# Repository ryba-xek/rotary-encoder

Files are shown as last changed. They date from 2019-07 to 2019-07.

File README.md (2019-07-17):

# rotation-sensor
Multipole AS5047D motor shaft sensor emulating standard UVW hall effect sensor signals

Please note, that AS5047d position is shifted by 1mm from the center of the board.

Emulates Hall sensors UVW signals for 14-pole BLDC motor.

## Building
`platformio run -e ATMEGA328P`

## Flashing
This code is supposed to be uploaded via standard AVR ISP programmer.
Please set fuses to `L=0xF7 H=0xD9 E=0xFF`

`avrdude -c usbasp -p m328p -P usb -e -U lfuse:w:0xF7:m -U hfuse:w:0xD9:m -U efuse:w:0xFF:m`

http://eleccelerator.com/fusecalc/fusecalc.php?chip=atmega328p&LOW=F7&HIGH=D9&EXTENDED=FF&LOCKBIT=FF

upload with `platformio run -t program -e ATMEGA328P`

## Testing
`platformio test -e native`

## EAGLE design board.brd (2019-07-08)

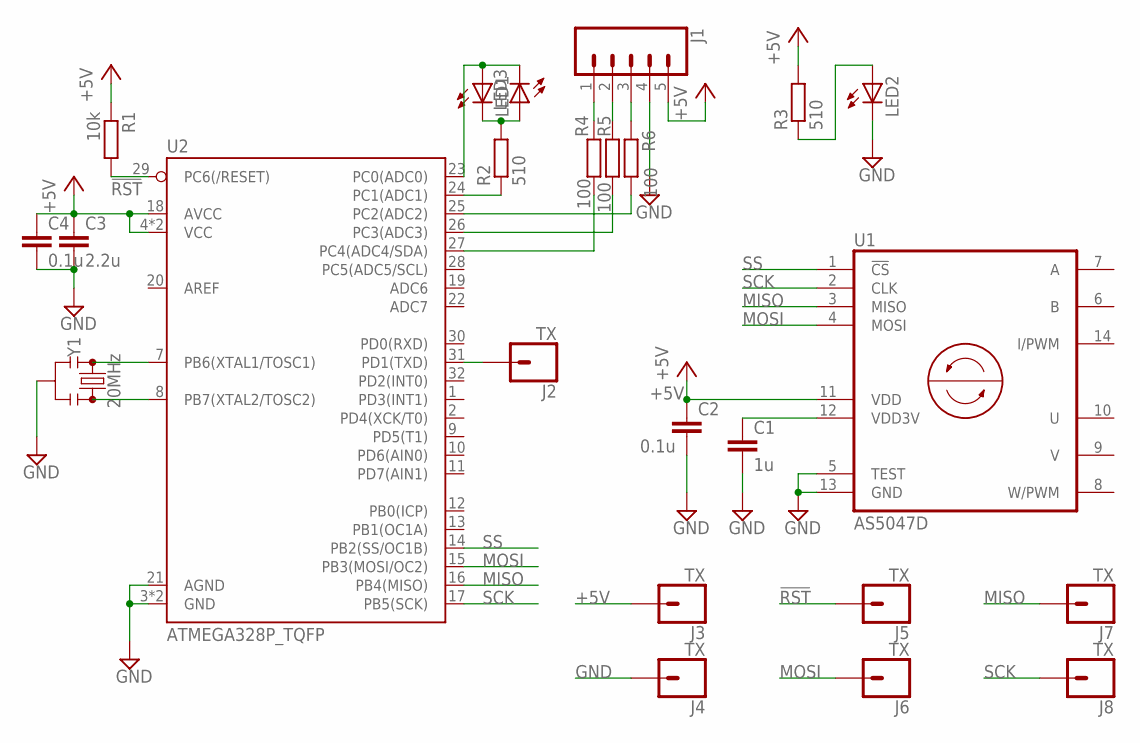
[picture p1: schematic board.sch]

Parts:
C1: 1u; C0603
C2, C4: 0.1u; C0603
C3: 2.2u; C0603
J1: CONN_05PTH_LONGPADS; 1X05_LONGPADS
J2, J3, J4, J5, J6, J7, J8: TX; 1X01_NO_SILK
LED1, LED2, LED3: LEDSML0805; SML0805
R1: 10k; R0603
R2, R3: 510; R0603
R4, R5, R6: 100; R0603
U1: AS5047D; TSSOP14
U2: ATMEGA328P_TQFP; TQFP32-08
Y1: 20MHz; CSTCE20M0V53-R0

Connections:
!RST: J5.1, R1.2, U2.29 (PC6(/RESET))
+5V: C2.1, C3.1, C4.1, J1.5, J3.1, R1.1, R3.2, U1.11 (VDD), U2.4 (VCC), U2.6 (VCC), U2.18 (AVCC)
GND: C1.2, C2.2, C3.2, C4.2, J1.4, J4.1, LED2.C, U1.5 (TEST), U1.13 (GND), U2.3 (GND), U2.5 (GND), U2.21 (AGND), Y1.2
MISO: J7.1, U1.3 (MISO), U2.16 (PB4(MISO))
MOSI: J6.1, U1.4 (MOSI), U2.15 (PB3(MOSI/OC2))
unnamed: U2.7 (PB6(XTAL1/TOSC1)), Y1.1
unnamed: U2.8 (PB7(XTAL2/TOSC2)), Y1.3
unnamed: R6.2, U2.25 (PC2(ADC2))
unnamed: R4.2, U2.27 (PC4(ADC4/SDA))
unnamed: R5.2, U2.26 (PC3(ADC3))
unnamed: LED1.A, LED3.C, U2.23 (PC0(ADC0))
unnamed: J1.1, R4.1
unnamed: LED2.A, R3.1
unnamed: J2.1, U2.31 (PD1(TXD))
unnamed: J1.2, R5.1
unnamed: R2.1, U2.24 (PC1(ADC1))
unnamed: LED1.C, LED3.A, R2.2
unnamed: J1.3, R6.1
SCK: J8.1, U1.2 (CLK), U2.17 (PB5(SCK))
SS: U1.1 (!CS!), U2.14 (PB2(SS/OC1B))
VDD3V: C1.1, U1.12 (VDD3V)

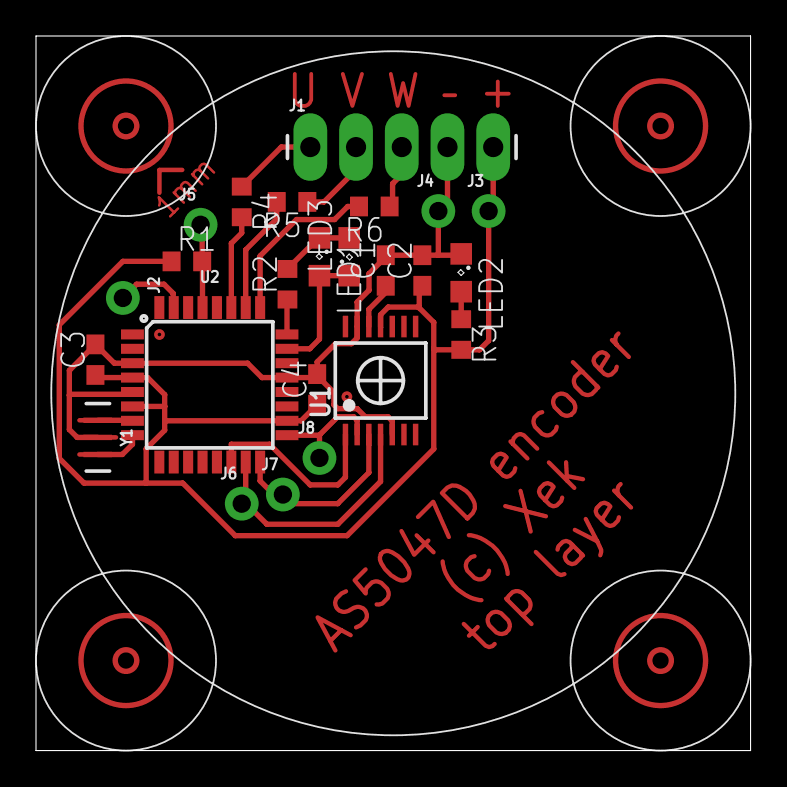
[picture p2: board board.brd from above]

Board: 2 copper layers, 39.7 x 39.7 mm, 24 parts (0 on the bottom side), 21 nets.

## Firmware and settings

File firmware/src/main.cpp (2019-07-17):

/**
 * This code generates UVW hall effect sensor signals from absolute shaft angle for a 14 pole pairs motor.
 * Simple hysteresis is used to avoid switching noise.
 */

#include <avr/io.h>
#include <util/delay.h>
#include <stdio.h>
#include <angledsp.h>
#include "main.h"
#include "as5047.h"


void USART_Init(void){
    // Set baud rate
    UBRR0 = BAUD_PRESCALE;

    // 115200,8,N,1
    UCSR0A = 1 << U2X0;
    UCSR0C = 1 << UCSZ00 | 1 << UCSZ01;
    UCSR0B = 1 << TXEN0;

}

void USART_SendByte(uint8_t u8Data){

    // Wait until last byte has been transmitted
    while((UCSR0A & (1<<UDRE0)) == 0) ;

    // Transmit data
    UDR0 = u8Data;
}

void USART_send_string(char s[])
{
    int i =0;

    while (s[i] != 0x00)
    {
        USART_SendByte((uint8_t) s[i]);
        i++;
    }
}

int main(void)
{
    uint16_t cycle = 0;
    uint8_t sector = 0;
    SensorReply r;

    USART_Init();
    initSensor();

    // output pins
    DDRC = 1 << PIN_LED1 | 1 << PIN_LED2 | 1 << PIN_W | 1 << PIN_V | 1 << PIN_U;
    DDRD = 1 << PIND1;

    #pragma clang diagnostic ignored "-Wmissing-noreturn"
    while (1)
    {
//        cycle++;

        r = readSensorAngle();
        if (r.success) {
            sector = calcSector(sector, normalizeAngle(r.data), HYSTERESIS);
        }

//        if (cycle >= 5000) {
//            char strBuf[256];
//            sprintf(strBuf, "[%u] %u - %u\n", sector, r.data, r.success);
//            USART_send_string(strBuf);
//            cycle = 0;
//        }

        // write outputs
//    if (!r.success || cordicError || !offsetCalibrated) {
//        // the state of UVW is frozen to 000
//        PORTC = (UVWVALUES[6] << 2) | 1;
//    } else {
        PORTC = (UVWVALUES[sector % 6]);// | magL << 1 | magH; // magL and magH can't both be true
//    }
//        _delay_us(1);
//        PORTC = ~PORTC;
//        _delay_us(1);
//        PORTC = ~PORTC;
    }

    return 0;
}

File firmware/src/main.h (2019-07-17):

//
// Created by xek on 05/07/2019.
//

#ifndef ROTARY_ENCODER_MAIN_H
#define ROTARY_ENCODER_MAIN_H

#include <stdint.h>
#include <avr/io.h>

#define PIN_LED1  PINC0
#define PIN_LED2  PINC1
#define PIN_W     PINC2
#define PIN_V     PINC3
#define PIN_U     PINC4

#define HYSTERESIS 1 // measured noise is around +/- 2.5, so 1—3 is recommended value
#define ZERO_SHIFT -1450

#define USART_BAUDRATE 115200
#define BAUD_PRESCALE ((F_CPU / 4 / USART_BAUDRATE - 1) / 2)

uint8_t UVWVALUES[7] = {
        0b10000,
        0b10100,
        0b00100,
        0b01100,
        0b01000,
        0b11000,
        0b00000, //error
};

uint8_t calcSector(uint8_t currSector, uint16_t angle);

#endif //ROTARY_ENCODER_MAIN_H

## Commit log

2019-07-07 board v1
    [board.brd, board.sch]
2019-07-08 Board v2
    [board.brd, board.sch]
2019-07-15 Alpha version for 14-pole motor
2019-07-17 Bugs fixed Unit tests
    [as5047.cpp, main.cpp, main.h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]
2019-07-17 Bug fixed, more tests
    [as5047.cpp, main.cpp]

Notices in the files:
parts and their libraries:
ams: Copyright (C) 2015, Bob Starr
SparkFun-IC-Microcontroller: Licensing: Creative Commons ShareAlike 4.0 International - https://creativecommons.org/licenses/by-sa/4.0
